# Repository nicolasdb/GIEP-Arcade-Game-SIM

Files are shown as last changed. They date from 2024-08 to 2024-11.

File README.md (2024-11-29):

# GIEP Arcade Game SIM

This arcade game is designed to raise awareness about the importance of effective rainwater management in urban areas, specifically in the context of the Integrated Management of Rainwater ([GIEP: Gestion intégrée des eaux pluviales](https://environnement.brussels/pro/agenda/gestion-integree-des-eaux-pluviales-et-vegetalisation-des-giep)) program in Brussels. 
GIEP aims to manage rainwater in a sustainable and integrated way, reducing flooding, improving water quality, and promoting urban biodiversity. The game highlights the challenges of conventional rainwater management, where urbanization and climate change lead to increased flooding, water pollution, and soil degradation. By simulating the impact of different rainwater management strategies, the game encourages players to think creatively about solutions that prioritize infiltration, reuse, and natural drainage, ultimately promoting a more ecological approach to urban water management.

## Features

- Main LED matrix display for visualizing the city and water flow
- Secondary LED array for additional visual feedback
- Interactive buttons for controlling GIEP devices
- Simulation of different rainfall intensities and water levels
- Game states including win and loss conditions
- Enhanced debugging capabilities
- Improved error handling and watchdog implementation

## Hardware Components

- ESP32 microcontroller
- WS2812B LED matrix (main display)
- WS2813 LED strip (secondary array)
- MCP23017 I/O expander for button inputs
- Various buttons for user interaction

## Software Components

- `main.cpp`: Main program entry point and task management
- `GameLogic`: Manages the game state and logic
- `Scene`: Handles the visual representation on the LED matrix
- `ButtonHandler`: Manages button inputs
- `MCP23017Handler`: Interfaces with the MCP23017 I/O expander
- `SecondaryLEDHandler`: Manages the secondary LED array
- `MatrixConfig`: Configures the LED matrix layout
- `StateTracker`: Tracks the overall system state
- `DebugLogger`: Provides logging functionality for debugging
- `config.h`: Contains hardware-specific configurations
- `game_config.h`: Contains game-specific configurations for easy adjustment

## Game Mechanics

1. The game simulates different rainfall intensities: idle, raining, heavy, and storm.
2. Players can activate GIEP devices using buttons to manage water flow.
3. Water levels in the sewer and basin are simulated and visualized.
4. Players can open/close the basin gate to transfer water between the sewer and basin.
5. The game ends in a win state if the player survives until the end of the storm, or in a loss state if the sewer overflows or the basin pollutes the river.

## Game Logic

The game progresses through the following states:

1. Waiting Phase:
   - The game cycles between WAITING_RAINING and WAITING_DRY states.
   - This phase serves as an attract mode to draw players' attention.

2. Active Gameplay:
   - Starts when a player presses any button during the waiting phase.
   - Progresses through RAINING, HEAVY, and STORM weather conditions.
   - Each weather condition has a specific duration and rain intensity.

3. Player Interactions:
   - Players can activate/deactivate 8 GIEP (Green Infrastructure Element) buttons.
   - Each active GIEP reduces the rate at which the sewer level increases.
   - Players can also control a basin gate to transfer water from the sewer to the basin.

4. Water Management:
   - The sewer level increases with rainfall and decreases with GIEP effects and natural drainage.
   - The basin level increases when the basin gate is open, transferring water from the sewer.
   - Players must balance the use of GIEPs and the basin gate to prevent overflow.

5. Win Condition:
   - Achieved when both sewer and basin levels are below a certain threshold after a storm.

6. Lose Conditions:
   - FLOOD: Occurs when the sewer level reaches its overflow threshold.
   - CANAL: Occurs when the basin level reaches its overflow threshold, polluting the river.

7. Game Over:
   - After a win or lose condition is met, the game displays the result for a set duration.
   - The game then automatically returns to the waiting phase, ready for the next player.

The game's difficulty progressively increases with each weather state, challenging players to use strategy and quick decision-making to manage the water levels effectively.

## Secondary LED Array

The secondary LED array provides additional visual feedback:

- 8 zones for GIEP device status
- 1 zone for basin gate status
- 3 zones for rainfall intensity levels
- 3 zones for end game states (flood death, pollution death, win)

## Building and Running

1. Ensure you have PlatformIO installed.
2. Clone this repository.
3. Open the project in PlatformIO.
4. Build and upload the project to your ESP32 board.

## Debugging

The project now includes enhanced debugging capabilities:
- Use the `DebugLogger` class to log messages at different levels (ERROR, WARN, INFO, DEBUG).
- Debug logs can be enabled or disabled using the DEBUG flag in the build configuration.
- The `config.h` file includes a DEBUG_PRINT macro for conditional debug output.

## Configuration

- Hardware-specific configurations are located in `config.h`.
- Game-specific parameters (e.g., timing, water levels, rain intensities) are now separated into `game_config.h` for easier adjustment.

## Failsafe Mechanisms

- Watchdog timer implementation to detect and recover from system hangs.
- Improved error handling in task creation and hardware initialization.

## Contributing

Contributions to improve the game or add new features are welcome. Please submit a pull request with your changes.

## License

This project is licensed under the MIT License. See the LICENSE file for details.

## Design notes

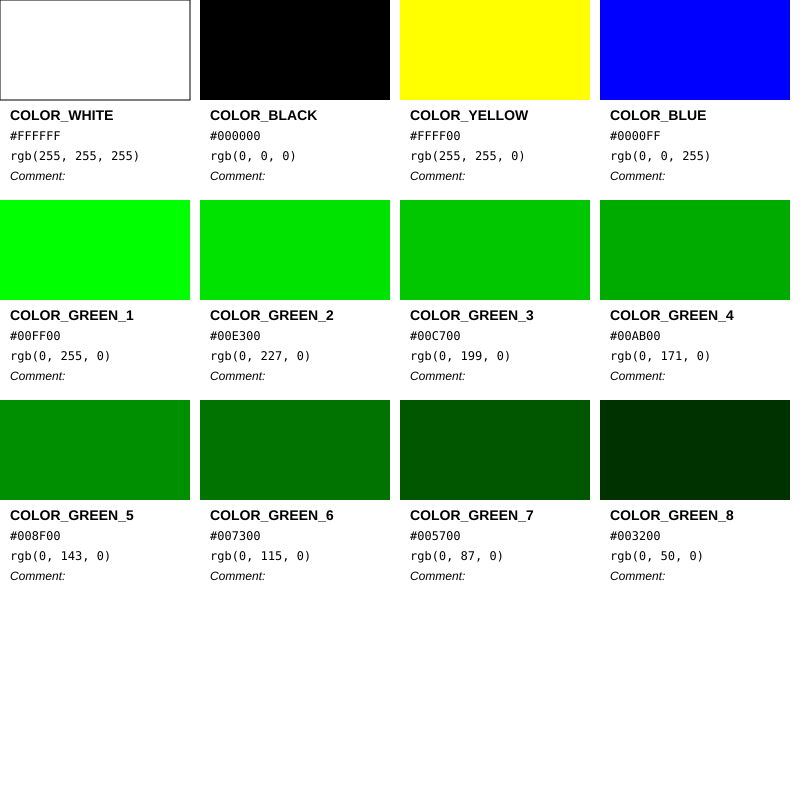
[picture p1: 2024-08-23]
include/color-palette.png

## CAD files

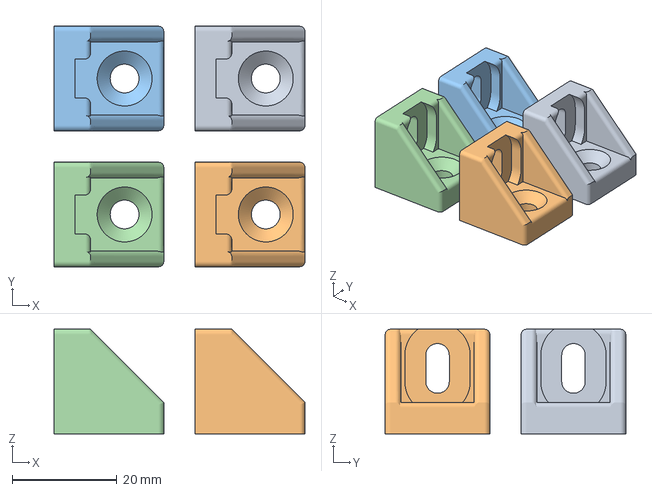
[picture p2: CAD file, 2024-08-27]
include/equerre alim v1.3mf
48.0 x 46.0 x 20.0 mm
equerre alim v1.stl x 4

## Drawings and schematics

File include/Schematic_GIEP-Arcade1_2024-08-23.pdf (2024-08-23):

## button arcade 68

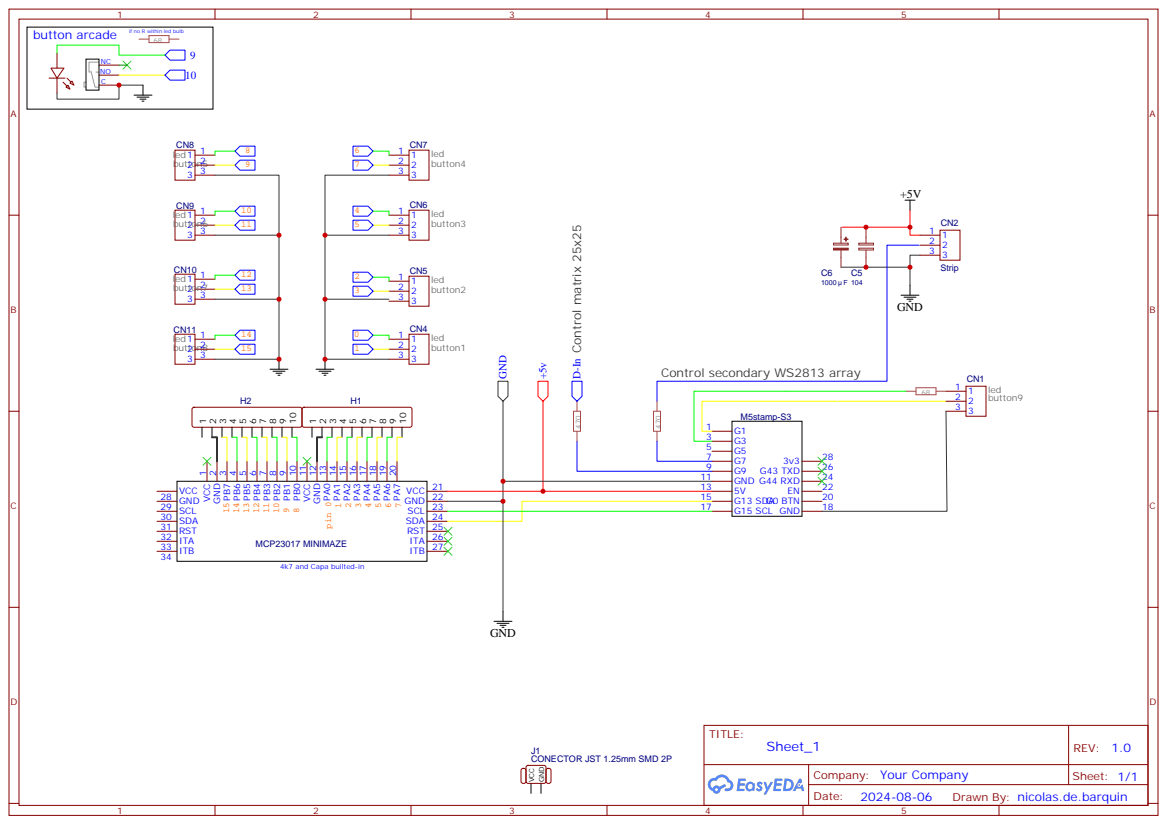
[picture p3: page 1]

if no R within led bulb

VCC 28 GND 29 SCL 30 SDA 31 RST 32 ITA 33 ITB 34

4k7 and Capa builted-in

Drawn By: nicolas.de.barquin

# WS2813 matrix 25x25

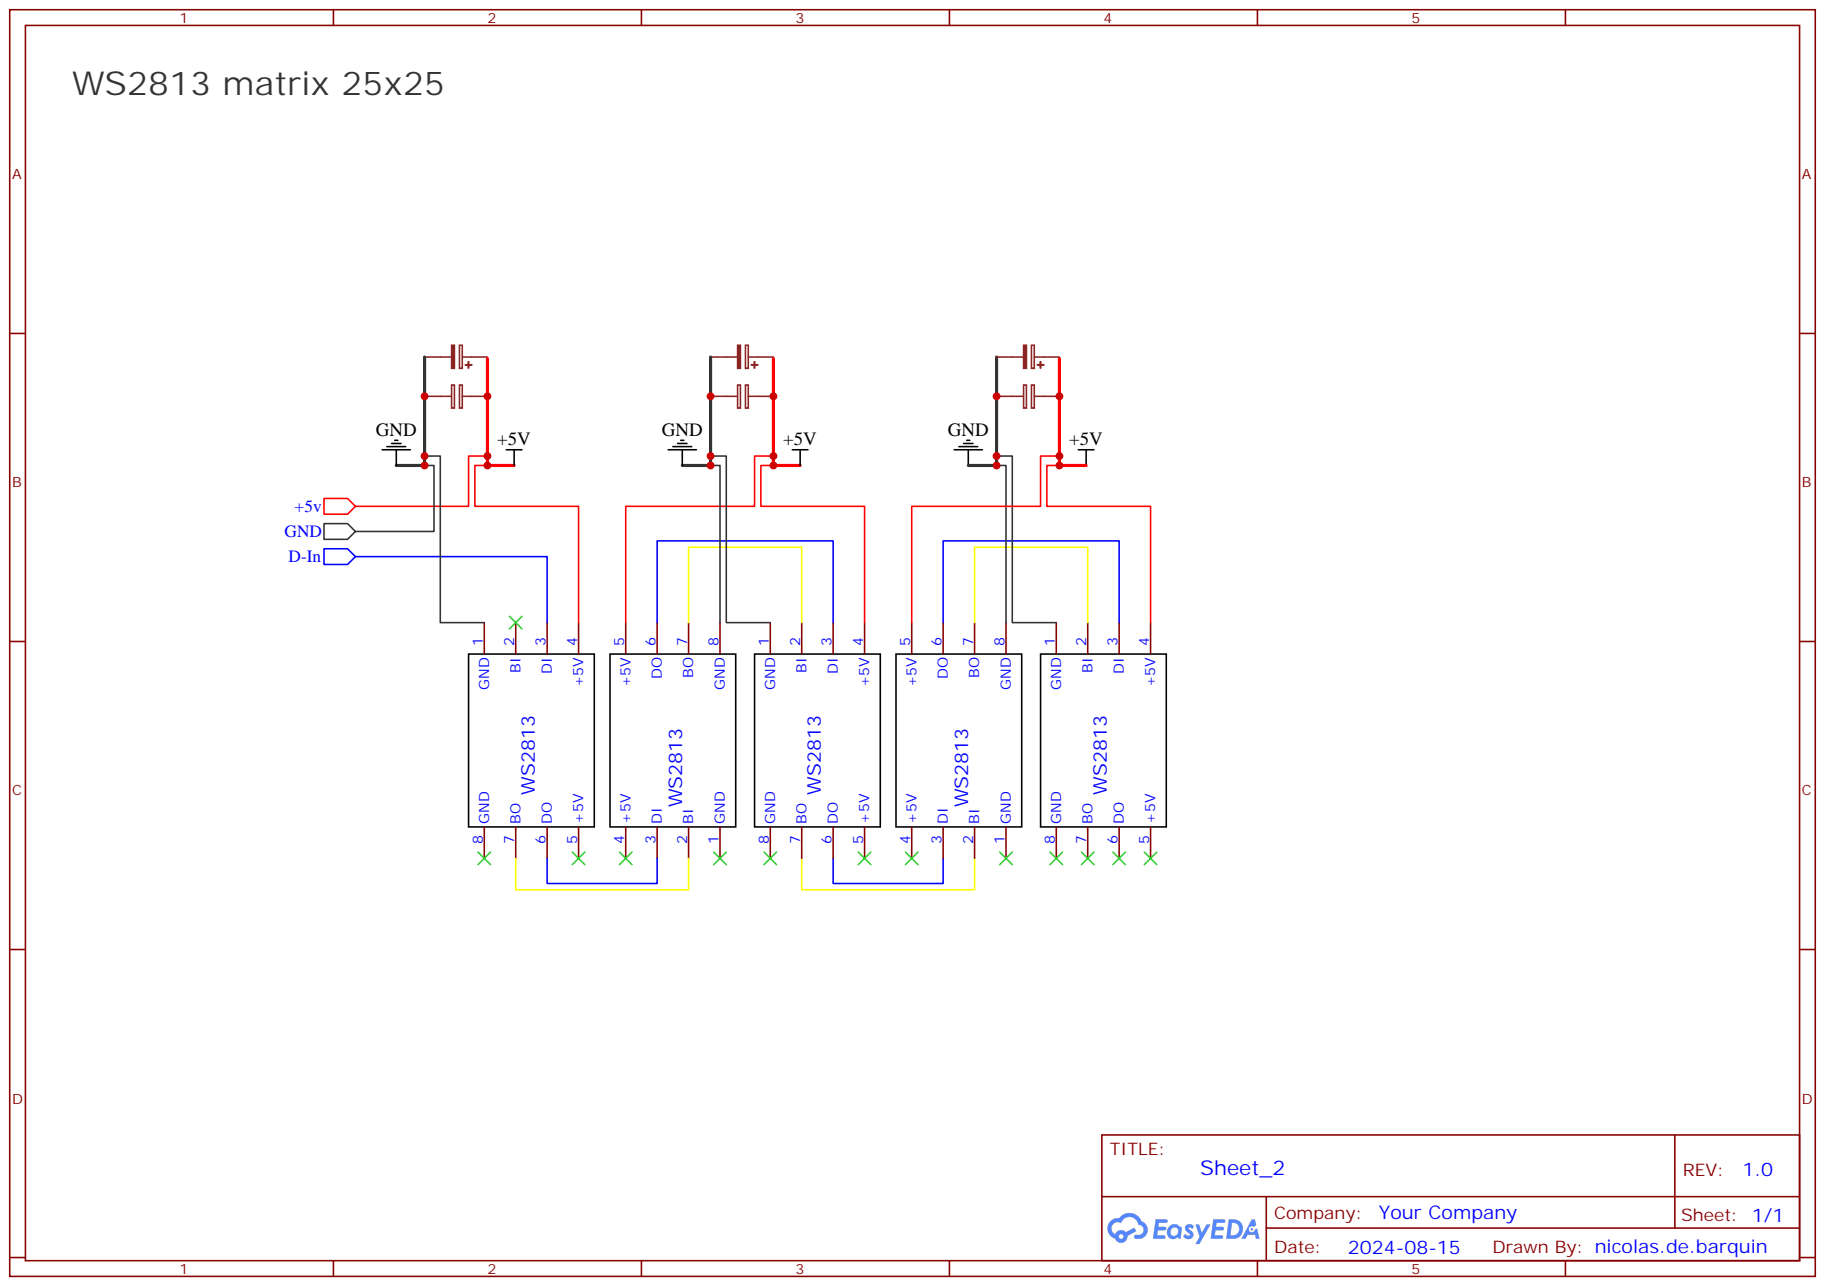
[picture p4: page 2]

Drawn By: nicolas.de.barquin

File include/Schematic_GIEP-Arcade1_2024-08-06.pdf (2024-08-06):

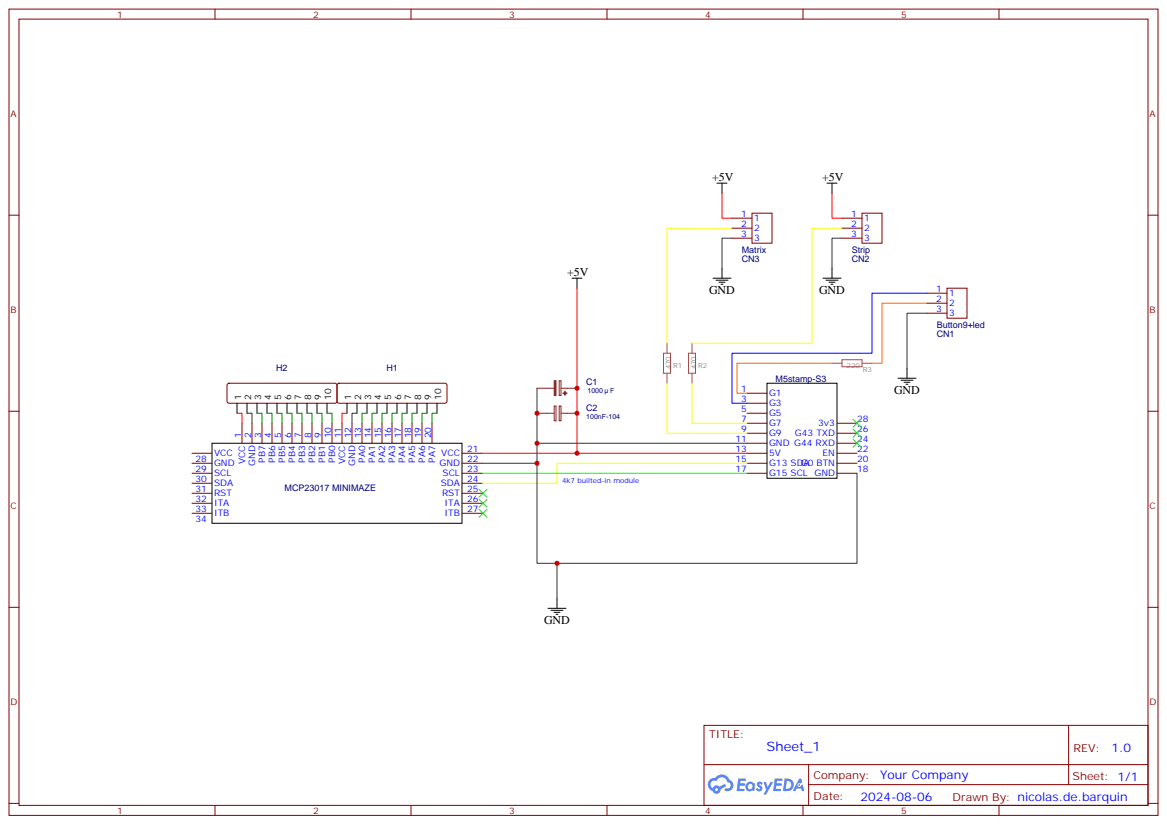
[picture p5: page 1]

VCC 28 GND 29 SCL 30 SDA 31 RST 32 ITA 33 ITB 34

Drawn By: nicolas.de.barquin

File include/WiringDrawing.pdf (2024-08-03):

# LEDs WS2813 - Matrix 25x25

# Meanwell

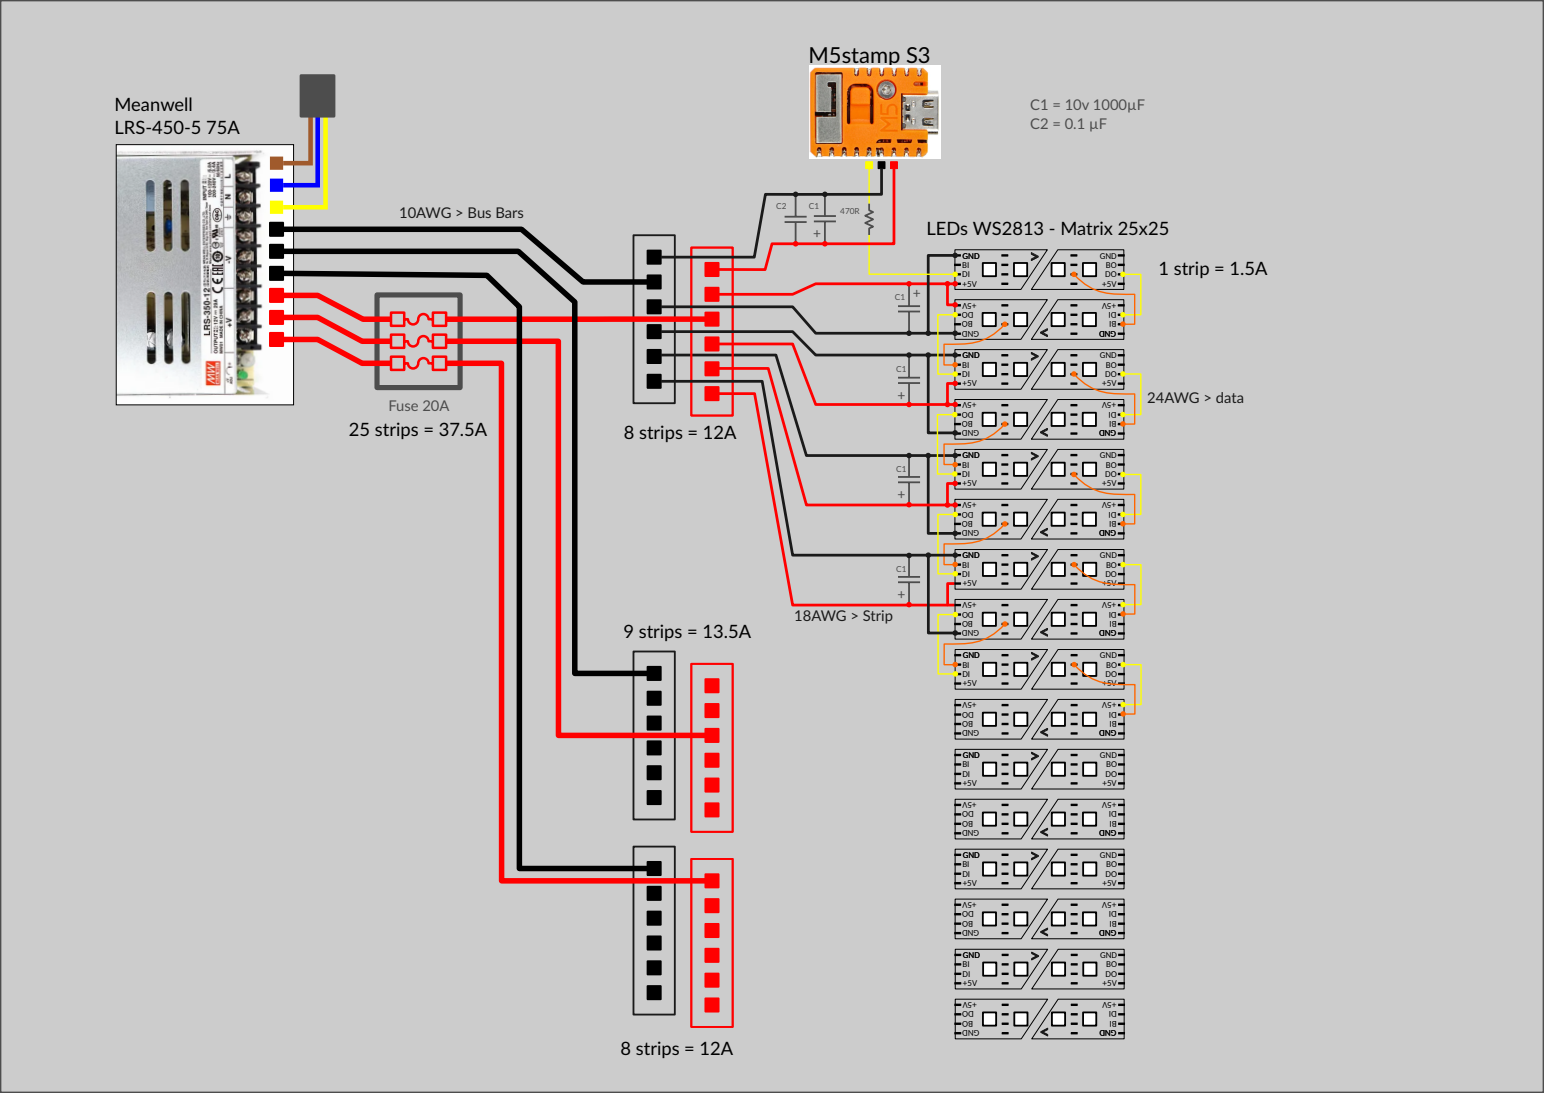
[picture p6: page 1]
GND; LRS-450-5 75A; M5stamp S3; 1 strip = 1.5A; Fuse 20A; 10AWG > Bus Bars; 8 strips = 12A; 9 strips = 13.5A; 18AWG > Strip; 24AWG > data; 25 strips = 37.5A

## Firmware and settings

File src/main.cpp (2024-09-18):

#include <Arduino.h>
#include <FastLED.h>
#include "freertos/FreeRTOS.h"
#include "freertos/task.h"
#include "DebugLogger.h"
#include "StateTracker.h"
#include "MatrixConfig.h"
#include "Scene.h"
#include "GameLogic.h"
#include "config.h"
#include "ButtonHandler.h"
#include "MCP23017Handler.h"
#include "SecondaryLEDHandler.h"

CRGB leds[NUM_LEDS];
MatrixConfig matrixConfig(MATRIX_WIDTH, MATRIX_HEIGHT, MATRIX_ORIENTATION, true);
Scene scene(matrixConfig);
SecondaryLEDHandler secondaryLEDs;
GameLogic gameLogic(scene, secondaryLEDs);
MCP23017Handler mcpHandler(MCP23017_ADDRESS);
ButtonHandler buttonHandler(mcpHandler, gameLogic);

void buttonTask(void* parameter) {
    TickType_t lastWakeTime = xTaskGetTickCount();
    const TickType_t frequency = pdMS_TO_TICKS(10);  // Check every 10ms

    while (true) {
        buttonHandler.update();
        vTaskDelayUntil(&lastWakeTime, frequency);
    }
}

void gameUpdateTask(void* parameter) {
    TickType_t lastWakeTime = xTaskGetTickCount();
    const TickType_t frequency = pdMS_TO_TICKS(33);  // Update every ~30fps

    while (true) {
        gameLogic.update();
        vTaskDelayUntil(&lastWakeTime, frequency);
    }
}

void ledUpdateTask(void* parameter) {
    TickType_t lastWakeTime = xTaskGetTickCount();
    const TickType_t frequency = pdMS_TO_TICKS(33);  // ~30fps

    while (true) {
        scene.update();
        scene.draw(leds);
        FastLED.show();
        secondaryLEDs.update();
        vTaskDelayUntil(&lastWakeTime, frequency);
    }
}

void setup() {
    Serial.begin(115200);
    
    // Wait for serial or timeout after 3 seconds
    unsigned long startTime = millis();
    while (!Serial && millis() - startTime < 3000) {
        ; // wait for serial port to connect. Needed for native USB port only
    }

    DebugLogger::init(Serial, LogLevel::CRITICAL);
    DebugLogger::critical("System initialized");

    pinMode(DEBUG_BUTTON_PIN, INPUT_PULLUP);
    pinMode(BASIN_GATE_BUTTON_PIN, INPUT_PULLUP);
    pinMode(BASIN_GATE_LED_PIN, OUTPUT);

    mcpHandler.begin();
    FastLED.addLeds<LED_TYPE, LED_PIN, COLOR_ORDER>(leds, NUM_LEDS).setCorrection(TypicalLEDStrip);
    FastLED.setBrightness(GameConfig::Brightness::GLOBAL_BRIGHTNESS);
    FastLED.clear();
    FastLED.show();
    secondaryLEDs.begin();
    scene.loadDefaultScene();

    BaseType_t result;
    result = xTaskCreatePinnedToCore(buttonTask, "ButtonTask", GameConfig::TaskConfig::BUTTON_TASK_STACK_SIZE, NULL, GameConfig::TaskConfig::BUTTON_TASK_PRIORITY, NULL, 0);
    if (result != pdPASS) {
        DebugLogger::critical("Failed to create ButtonTask: %d", result);
    }
    result = xTaskCreatePinnedToCore(gameUpdateTask, "GameUpdateTask", GameConfig::TaskConfig::GAME_UPDATE_TASK_STACK_SIZE, NULL, GameConfig::TaskConfig::GAME_UPDATE_TASK_PRIORITY, NULL, 1);
    if (result != pdPASS) {
        DebugLogger::critical("Failed to create GameUpdateTask: %d", result);
    }
    result = xTaskCreatePinnedToCore(ledUpdateTask, "LEDUpdateTask", GameConfig::TaskConfig::LED_UPDATE_TASK_STACK_SIZE, NULL, GameConfig::TaskConfig::LED_UPDATE_TASK_PRIORITY, NULL, 1);
    if (result != pdPASS) {
        DebugLogger::critical("Failed to create LEDUpdateTask: %d", result);
    }

    DebugLogger::critical("Setup complete");
}

void loop() {
    // Empty, as tasks are handling everything
    vTaskDelay(pdMS_TO_TICKS(1000));  // Delay for 1 second
}

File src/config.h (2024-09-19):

#pragma once
#include <FastLED.h>
#include "game_config.h"

// Debug configuration
#ifdef DEBUG
#define DEBUG_PRINT(x) Serial.println(x)
#else
#define DEBUG_PRINT(x)
#endif

// Hardware configuration
#define LED_PIN 9
#define MATRIX_WIDTH 25
#define MATRIX_HEIGHT 25
#define NUM_LEDS (MATRIX_WIDTH * MATRIX_HEIGHT)
#define LED_TYPE WS2813
#define COLOR_ORDER GRB
#define MATRIX_ORIENTATION MatrixOrientation::TOP_LEFT_VERTICAL

// MCP23017 configuration
#define MCP23017_ADDRESS 0x20
#define NUM_MCP_BUTTONS 8
#define TOTAL_BUTTONS 9
#define BASIN_GATE_BUTTON_PIN 1
#define BASIN_GATE_LED_PIN 3
#define DEBUG_BUTTON_PIN 0

// Global switch for button LEDs (including button 9)
#define USE_BUTTON_LEDS false

// Watchdog configuration
#define WDT_TIMEOUT 15  // 15 seconds

// Consolidated color definitions
enum ZoneColors {
    COLOR_WHITE = 0xFFFFFF,
    COLOR_BLACK = 0x000000,
    COLOR_GREEN_1 = 0x00FF00,
    COLOR_GREEN_2 = 0x00E300,
    COLOR_GREEN_3 = 0x00C700,
    COLOR_GREEN_4 = 0x00AB00,
    COLOR_GREEN_5 = 0x008F00,
    COLOR_GREEN_6 = 0x007300,
    COLOR_GREEN_7 = 0x005700,
    COLOR_GREEN_8 = 0x003200,
    COLOR_YELLOW = 0xFFFF00,
    COLOR_BLUE = 0x0000FF,
    COLOR_RED = 0xFF0000,
    COLOR_MAGENTA = 0xFF00FF,
    COLOR_PURPLE = 0x6400FF,
    COLOR_DARK_BLUE = 0x0000E3,     // Used for Rain Level 1
    COLOR_MEDIUM_BLUE = 0x0000C7,   // Used for Rain Level 2
    COLOR_LIGHT_BLUE = 0x0000AB,    // Used for Rain Level 3
    COLOR_DARK_RED = 0xC70000,      // Used for Flood Death
    COLOR_MEDIUM_RED = 0xAB0000,    // Used for Pollution Death
    COLOR_CYAN = 0x00FFFF,          // Used for Win condition
};

// Default bitmap for the scene
const uint32_t DEFAULT_BITMAP[625] = {
    0xFFFFFF, 0xFFFFFF, 0xFFFFFF, 0xFFFFFF, 0xFFFFFF, 0xFFFFFF, 0xFFFFFF, 0xFFFFFF, 0xFFFFFF, 0xFFFFFF, 0xFFFFFF, 0xFFFFFF, 0xFFFFFF, 0xFFFFFF, 0xFFFFFF, 0xFFFFFF, 0xFFFFFF, 0xFFFFFF, 0xFFFFFF, 0xFFFFFF, 0xFFFFFF, 0xFFFFFF, 0xFFFFFF, 0xFFFFFF, 0xFFFFFF, 
    0xFFFFFF, 0xFFFFFF, 0xFFFFFF, 0xFFFFFF, 0xFFFFFF, 0xFFFFFF, 0xFFFFFF, 0xFFFFFF, 0xFFFFFF, 0xFFFFFF, 0xFFFFFF, 0xFFFFFF, 0xFFFFFF, 0xFFFFFF, 0xFFFFFF, 0xFFFFFF, 0xFFFFFF, 0xFFFFFF, 0xFFFFFF, 0xFFFFFF, 0xFFFFFF, 0x008F00, 0x008F00, 0x008F00, 0x008F00, 
    0xFFFFFF, 0xFFFFFF, 0xFFFFFF, 0xFFFFFF, 0xFFFFFF, 0xFFFFFF, 0xFFFFFF, 0x00FF00, 0x00FF00, 0x00FF00, 0xFFFFFF, 0xFFFFFF, 0xFFFFFF, 0xFFFFFF, 0xFFFFFF, 0xFFFFFF, 0xFFFFFF, 0xFFFFFF, 0x008F00, 0x008F00, 0x008F00, 0x008F00, 0x008F00, 0x008F00, 0x008F00, 
    0xFFFFFF, 0xFFFFFF, 0xFFFFFF, 0xFFFFFF, 0xFFFFFF, 0xFFFFFF, 0x00FF00, 0x00FF00, 0x00FF00, 0x00FF00, 0xFFFFFF, 0xFFFFFF, 0xFFFFFF, 0xFFFFFF, 0xFFFFFF, 0xFFFFFF, 0xFFFFFF, 0x008F00, 0x008F00, 0x008F00, 0x008F00, 0x008F00, 0x008F00, 0x008F00, 0x008F00, 
    0xFFFFFF, 0xFFFFFF, 0xFFFFFF, 0xFFFFFF, 0xFFFFFF, 0xFFFFFF, 0xFFFFFF, 0xFFFFFF, 0xFFFFFF, 0xFFFFFF, 0xFFFFFF, 0xFFFFFF, 0xFFFFFF, 0x008F00, 0x008F00, 0x008F00, 0x008F00, 0x008F00, 0x008F00, 0x008F00, 0x008F00, 0x008F00, 0x008F00, 0x008F00, 0x008F00, 
    0xFFFFFF, 0xFFFFFF, 0xFFFFFF, 0xFFFFFF, 0xFFFFFF, 0xFFFFFF, 0xFFFFFF, 0xFFFFFF, 0xFFFFFF, 0xFFFFFF, 0xFFFFFF, 0xFFFFFF, 0xFFFFFF, 0xFFFFFF, 0x008F00, 0x008F00, 0xFFFFFF, 0xFFFFFF, 0xFFFFFF, 0xFFFFFF, 0xFFFFFF, 0xFFFFFF, 0xFFFFFF, 0xFFFFFF, 0xFFFFFF, 
    0xFFFFFF, 0xFFFFFF, 0xFFFFFF, 0xFFFFFF, 0xFFFFFF, 0xFFFFFF, 0xFFFFFF, 0xFFFFFF, 0xFFFFFF, 0xFFFFFF, 0xFFFFFF, 0xFFFFFF, 0xFFFFFF, 0xFFFFFF, 0x008F00, 0x008F00, 0xFFFFFF, 0xFFFFFF, 0xFFFFFF, 0xFFFFFF, 0xFFFFFF, 0xFFFFFF, 0xFFFFFF, 0xFFFFFF, 0xFFFFFF, 
    0xFFFFFF, 0xFFFFFF, 0xFFFFFF, 0xFFFFFF, 0xFFFFFF, 0xFFFFFF, 0xFFFFFF, 0xFFFFFF, 0xFFFFFF, 0xFFFFFF, 0xFFFFFF, 0xFFFFFF, 0xFFFFFF, 0xFFFFFF, 0x00E300, 0x008F00, 0xFFFFFF, 0xFFFFFF, 0xFFFFFF, 0xFFFFFF, 0xFFFFFF, 0xFFFFFF, 0xFFFFFF, 0xFFFFFF, 0xFFFFFF, 
    0xFFFFFF, 0xFFFFFF, 0xFFFFFF, 0xFFFFFF, 0xFFFFFF, 0xFFFFFF, 0xFFFFFF, 0xFFFFFF, 0xFFFFFF, 0x00C700, 0x00C700, 0x00C700, 0xFFFFFF, 0xFFFFFF, 0x00E300, 0xFFFFFF, 0xFFFFFF, 0xFFFFFF, 0xFFFFFF, 0xFFFFFF, 0xFFFFFF, 0xFFFFFF, 0xFFFFFF, 0xFFFFFF, 0xFFFFFF, 
    0xFFFFFF, 0xFFFFFF, 0xFFFFFF, 0xFFFFFF, 0xFFFFFF, 0xFFFFFF, 0xFFFFFF, 0xFFFFFF, 0x00C700, 0x00C700, 0x00C700, 0x00C700, 0xFFFFFF, 0xFFFFFF, 0xFFFFFF, 0xFFFFFF, 0xFFFFFF, 0xFFFFFF, 0xFFFFFF, 0xFFFFFF, 0xFFFFFF, 0xFFFFFF, 0xFFFFFF, 0xFFFFFF, 0xFFFFFF, 
    0xFFFFFF, 0xFFFFFF, 0xFFFFFF, 0x00AB00, 0x00AB00, 0x00AB00, 0xFFFFFF, 0xFFFFFF, 0x00C700, 0x00C700, 0x00C700, 0x00C700, 0xFFFFFF, 0xFFFFFF, 0xFFFFFF, 0xFFFFFF, 0xFFFFFF, 0xFFFFFF, 0xFFFFFF, 0x007300, 0x007300, 0x007300, 0x007300, 0x007300, 0x007300, 
    0xFFFFFF, 0xFFFFFF, 0x00AB00, 0x00AB00, 0x00AB00, 0x00AB00, 0xFFFFFF, 0xFFFFFF, 0x00C700, 0x00C700, 0x00C700, 0x00C700, 0x005700, 0x005700, 0x005700, 0x005700, 0xFFFFFF, 0xFFFFFF, 0xFFFFFF, 0x007300, 0x007300, 0x007300, 0x007300, 0x007300, 0x007300,
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

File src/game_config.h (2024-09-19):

#pragma once
#include <cstdint>

namespace GameConfig {
    namespace Timing {
        constexpr uint32_t WAITING_RAINING_DURATION = 10000;
        constexpr uint32_t WAITING_DRY_DURATION = 10000;
        constexpr uint32_t RAINING_DURATION = 10000;
        constexpr uint32_t HEAVY_DURATION = 15000;
        constexpr uint32_t STORM_DURATION = 15000;
        constexpr uint32_t END_STATE_DURATION = 5000;
    }

    namespace SewerMechanics {
        constexpr float SEWER_INCREASE_RATE_RAINING = 0.013f;
        constexpr float SEWER_INCREASE_RATE_HEAVY = 0.02f;
        constexpr float SEWER_INCREASE_RATE_STORM = 0.035f;
        constexpr float GIEP_EFFECT_STRENGTH = 0.0045f;
        constexpr float SEWER_DRAIN_RATE = 0.01f;
        constexpr float BASIN_GATE_TRANSFER_RATE = 0.007f;
    }

    namespace GameBalance {
        constexpr float SEWER_OVERFLOW_THRESHOLD = 0.65f;  // Changed back to 0.65
        constexpr float BASIN_OVERFLOW_THRESHOLD = 0.95f;  // Changed to 0.95
        constexpr float OVERFLOW_ACTIVATION_THRESHOLD = 0.8f;  // New threshold for overflow activation
        constexpr float WIN_THRESHOLD = 0.5f;
    }

    namespace RainVisuals {
        constexpr float RAIN_INTENSITY_RAINING = 0.005f;
        constexpr float RAIN_INTENSITY_HEAVY = 0.03f;
        constexpr float RAIN_INTENSITY_STORM = 0.10f;
        constexpr uint8_t RAIN_MAX_TRAIL_LENGTH = 4;
        constexpr float RAIN_HEAVY_MULTIPLIER = 10.0f;
        constexpr float RAIN_STORM_MULTIPLIER = 30.0f;
        constexpr uint8_t RAIN_STORM_WIND_CHANCE = 100; // 90% chance (out of 255)
    }

    namespace Brightness {
        constexpr uint8_t GLOBAL_BRIGHTNESS = 30;
        constexpr uint8_t ACTIVE_BRIGHTNESS = 16;
        constexpr uint8_t GIEP_ACTIVE_BRIGHTNESS = 255;
        constexpr uint8_t GIEP_INACTIVE_BRIGHTNESS = 30;
        constexpr uint8_t RAIN_BRIGHTNESS = 190;
        constexpr uint8_t SEWER_BRIGHTNESS = 255;
        constexpr uint8_t SEWER_EMPTY_BRIGHTNESS = ACTIVE_BRIGHTNESS;
        constexpr uint8_t BASIN_BRIGHTNESS = 255;
        constexpr uint8_t BASIN_EMPTY_BRIGHTNESS = 12;
        constexpr uint8_t BASIN_GATE_BRIGHTNESS = 255;
        constexpr uint8_t BASIN_GATE_INACTIVE_BRIGHTNESS = 40;
        constexpr uint8_t BASIN_OVERFLOW_BRIGHTNESS = 255;
        constexpr uint8_t RIVER_BRIGHTNESS = 255;
        constexpr uint8_t FLOOD_SEWER_BRIGHTNESS = 255;  // New brightness for flood state
    }

    namespace Animation {
        constexpr uint32_t BLINK_DURATION = 500; // milliseconds
    }

    namespace TaskConfig {
        constexpr uint32_t BUTTON_TASK_STACK_SIZE = 2048;
        constexpr uint32_t GAME_UPDATE_TASK_STACK_SIZE = 4096;
        constexpr uint32_t LED_UPDATE_TASK_STACK_SIZE = 2048;
        constexpr uint8_t BUTTON_TASK_PRIORITY = 3;
        constexpr uint8_t GAME_UPDATE_TASK_PRIORITY = 2;
        constexpr uint8_t LED_UPDATE_TASK_PRIORITY = 1;
    }
}

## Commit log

2024-07-26 debug mode ok with button and scene from bitmap
2024-07-27 4 buttons
2024-08-03 add wiring map
2024-08-03 update wiring single strips
2024-08-07 update wiring
2024-08-12 update wiring with PCB
2024-08-15 add 3D for PSU
    [equerre alim v1.3mf]
2024-08-27 update included extra
    [equerre alim v1.3mf]
2024-08-27 add secondary buttons and adjust to map
2024-08-29 add schema secondary LEDS
2024-09-09 almost setup leds.
2024-09-18 3 stages ok
2024-09-18 giep button activate on first push
